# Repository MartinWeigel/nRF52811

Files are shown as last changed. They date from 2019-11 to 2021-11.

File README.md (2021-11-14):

# nRF52811 PCB

This is the schematics and footprint of a basic board with the [nRF52811 microcontroller](https://www.nordicsemi.com/?sc_itemid=%7B7CBDF55C-9745-4A7D-A491-5B66AE9454B6%7D
) from [Nordic Semiconductor](https://devzone.nordicsemi.com). This microcontroller supports Bluetooth Low Energy 5.1. The board contains one LED and can be powered either over Micro-USB or a Li-Po battery. It requires a SWD-capable programmer for programming and debugging.

The board was primarily designed for testing and familiarizing myself with [KiCad 5.1](http://www.kicad.org).

## Design
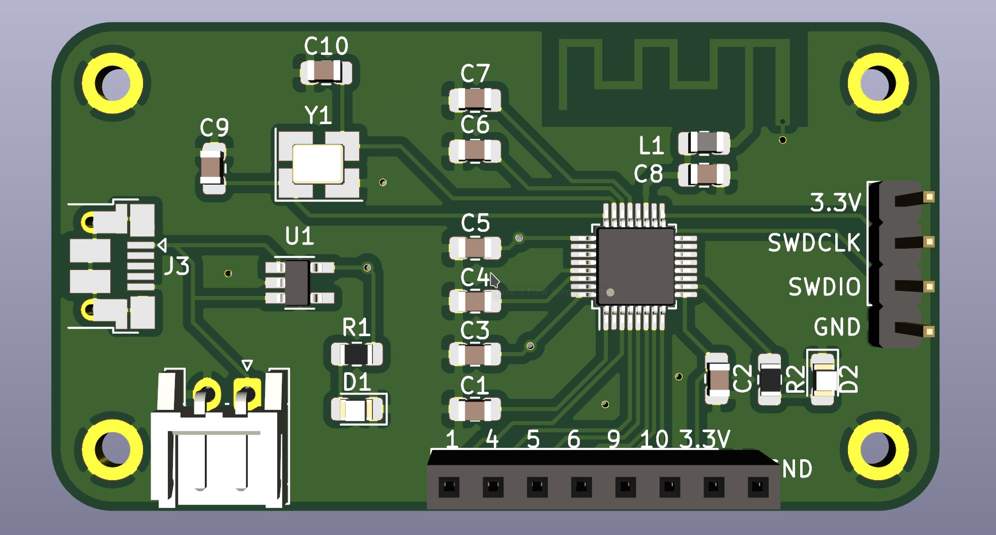
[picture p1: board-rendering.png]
Rendering of the board


## License
<br />This work is licensed under a <a rel="license" href="http://creativecommons.org/licenses/by/4.0/">Creative Commons Attribution 4.0 International License</a>.

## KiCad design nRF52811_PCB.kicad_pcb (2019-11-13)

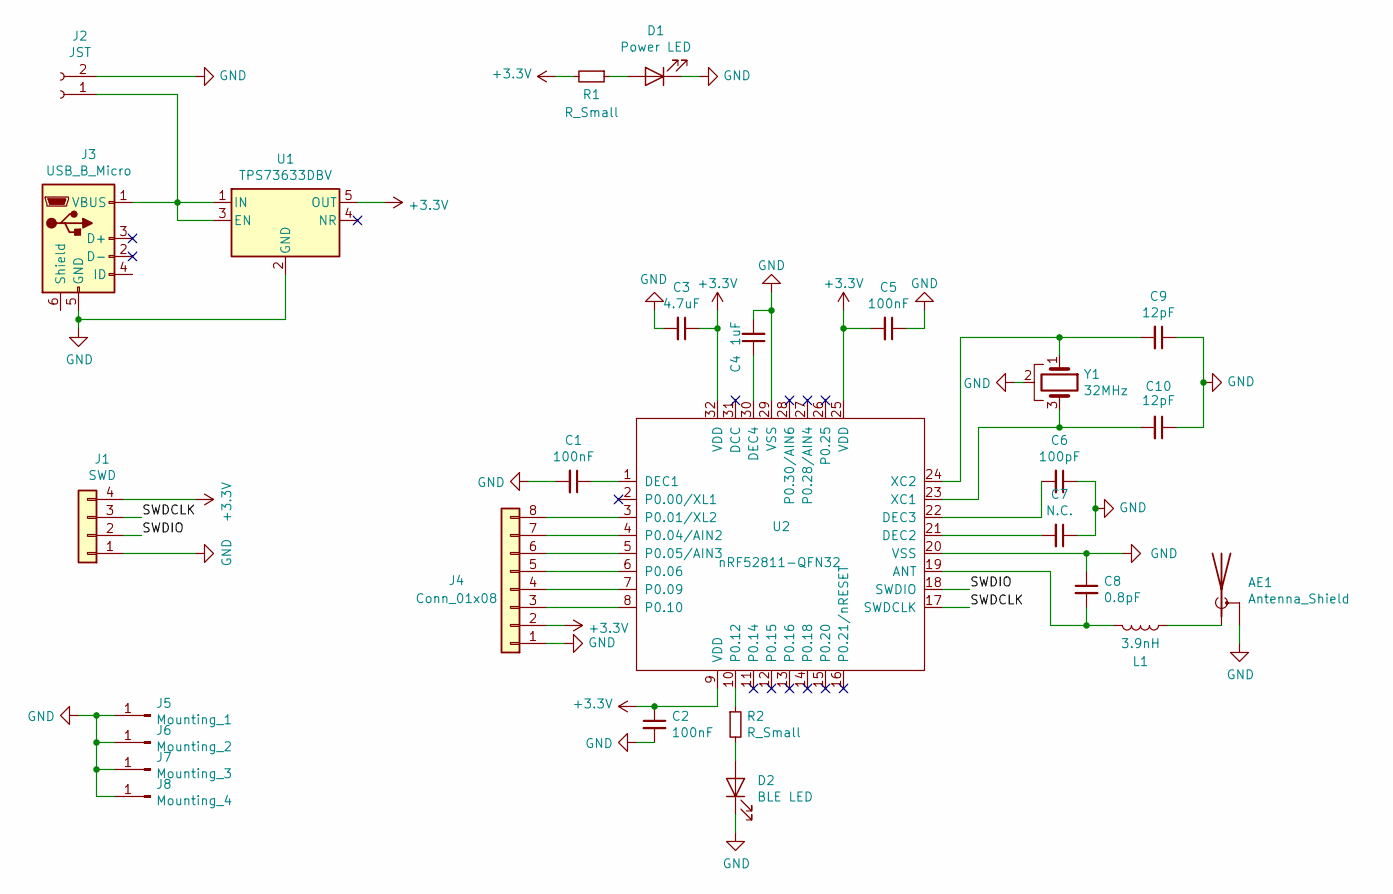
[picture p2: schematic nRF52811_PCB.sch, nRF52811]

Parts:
AE1: Antenna_Shield; Texas_SWRA117D_2.4GHz_Left
C1, C2, C5: 100nF; C_0805_2012Metric_Pad1.15x1.40mm_HandSolder
C3: 4.7uF; C_0805_2012Metric_Pad1.15x1.40mm_HandSolder
C4: 1uF; C_0805_2012Metric_Pad1.15x1.40mm_HandSolder
C6: 100pF; C_0805_2012Metric_Pad1.15x1.40mm_HandSolder
C7: N.C.; C_0805_2012Metric_Pad1.15x1.40mm_HandSolder
C8: 0.8pF; C_0805_2012Metric_Pad1.15x1.40mm_HandSolder
C9, C10: 12pF; C_0805_2012Metric_Pad1.15x1.40mm_HandSolder
D1: Power LED; LED_0805_2012Metric_Pad1.15x1.40mm_HandSolder
D2: BLE LED; LED_0805_2012Metric_Pad1.15x1.40mm_HandSolder
J1: SWD; PinHeader_1x04_P2.54mm_Vertical
J2: JST; JST_EH_S2B-EH_1x02_P2.50mm_Horizontal
J3: USB_B_Micro; USB_Micro-B_Amphenol_10103594-0001LF_Horizontal
J4: Conn_01x08; PinSocket_1x08_P2.54mm_Vertical
J5: Mounting_1; MountingHole_2.2mm_M2_DIN965_Pad
J6: Mounting_2; MountingHole_2.2mm_M2_DIN965_Pad
J7: Mounting_3; MountingHole_2.2mm_M2_DIN965_Pad
J8: Mounting_4; MountingHole_2.2mm_M2_DIN965_Pad
L1: 3.9nH; L_0805_2012Metric_Pad1.15x1.40mm_HandSolder
R1, R2: R_Small; R_0805_2012Metric_Pad1.15x1.40mm_HandSolder
U1: TPS73633DBV; SOT-23-5_HandSoldering
U2: nRF52811-QFN32; LQFP-32_5x5mm_P0.5mm
Y1: 32MHz; Crystal_SMD_3225-4Pin_3.2x2.5mm_HandSoldering

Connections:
+3V3: C2.1, C3.1, C5.2, J1.4, J4.2, R1.2, U1.5 (OUT), U2.9 (VDD), U2.25 (VDD), U2.32 (VDD)
/SWDCLK: J1.3, U2.17 (SWDCLK)
/SWDIO: J1.2, U2.18 (SWDIO)
GND: AE1.2 (Shield), C1.2, C2.2, C3.2, C4.2, C5.1, C6.1, C7.1, C8.1, C9.1, C10.1, D1.1 (K), D2.1 (K), J1.1, J2.2, J3.5 (GND), J4.1, J5.1, J6.1, J7.1, J8.1, U1.2 (GND), U2.20 (VSS), U2.29 (VSS), Y1.2
unnamed: AE1.1 (A), L1.1
unnamed: C1.1, U2.1 (DEC1)
unnamed: C4.1, U2.30 (DEC4)
unnamed: C6.2, U2.22 (DEC3)
unnamed: C7.2, U2.21 (DEC2)
unnamed: C8.2, L1.2, U2.19 (ANT)
unnamed: C9.2, U2.24 (XC2), Y1.1
unnamed: C10.2, U2.23 (XC1), Y1.3
unnamed: D1.2 (A), R1.1
unnamed: D2.2 (A), R2.2
unnamed: J2.1, J3.1 (VBUS), U1.1 (IN), U1.3 (EN)
unnamed: J4.3, U2.8 (P0.10)
unnamed: J4.4, U2.7 (P0.09)
unnamed: J4.5, U2.6 (P0.06)
unnamed: J4.6, U2.5 (P0.05/AIN3)
unnamed: J4.7, U2.4 (P0.04/AIN2)
unnamed: J4.8, U2.3 (P0.01/XL2)
unnamed: R2.1, U2.10 (P0.12)

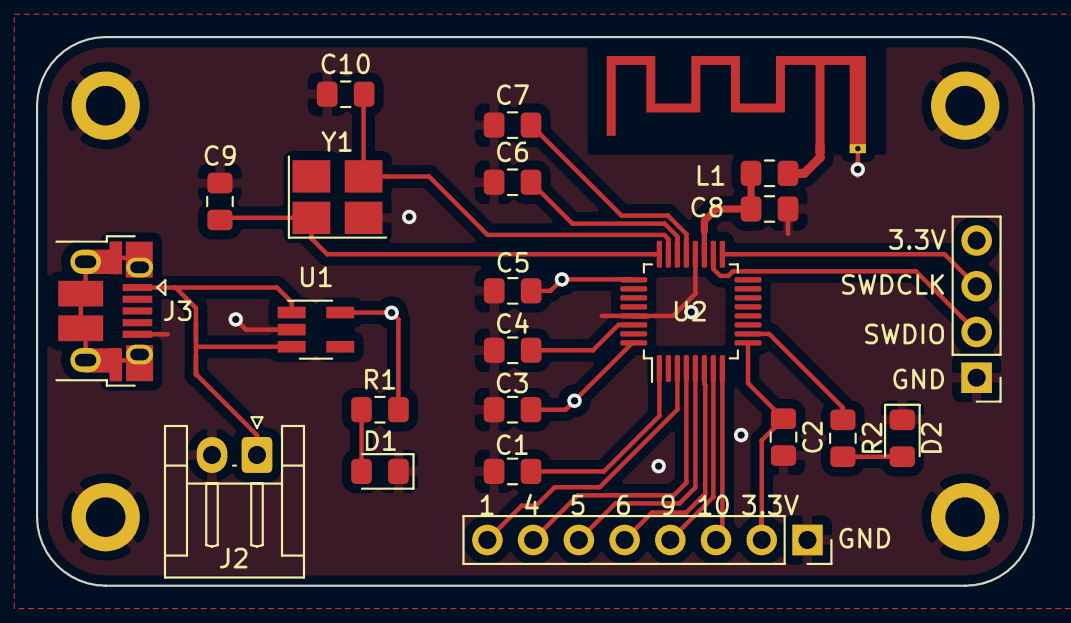
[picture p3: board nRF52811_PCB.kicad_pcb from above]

Board: 4 copper layers, 55.4 x 30.5 mm, 27 parts (0 on the bottom side), 22 nets.

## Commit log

2019-10-24 Version 1
    [nRF52811_PCB.kicad_pcb, nRF52811_PCB.sch]
2019-11-13 Added all pin names in nRF52811 library
    [nRF52811_PCB.kicad_pcb, nRF52811_PCB.sch]
2021-11-10 Update README.md
    https://forum.kicad.info/t/warning-avoid-all-links-to-kicad-pcb-org-use-kicad-org/31521

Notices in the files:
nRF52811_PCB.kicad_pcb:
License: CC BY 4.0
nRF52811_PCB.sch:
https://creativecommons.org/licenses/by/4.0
